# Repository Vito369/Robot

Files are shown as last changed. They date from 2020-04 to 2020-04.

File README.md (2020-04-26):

# Robot

## Authoři

Piskoř Dominik, Tkadlec Prokop, Vitoslavský Ondřej,Viater Dominik

## Úvod

Cílem práce je navrhnout autonomního mobilního robota, který dokáže sledovat černou
izolační pásku na bílém podkladu. Zároveň dokáže kamerou snímat překážky vyskytující se na
pásce a srážet je nebo se jim vyhýbat v závislosti na typu překážky. Překážky jsou dvojího
typu a to zombie (zelená překážka) a silničář (červená překážka).

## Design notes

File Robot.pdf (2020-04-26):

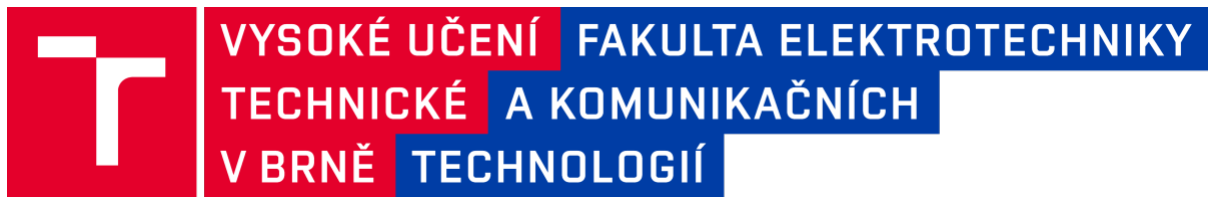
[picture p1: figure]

# Autonomní mobilní robot

## Tým: Snad dojedem

Autoři: | Vitoslavský Ondřej Piskoř Dominik Tkadlec Prokop Viater Dominik

# Obsah

# Úvod

Cílem práce je navrhnout autonomního mobilního robota, který dokáže sledovat černou izolační pásku na bílém podkladu. Zároveň dokáže kamerou snímat překážky vyskytující se na pásce a srážet je nebo se jim vyhýbat v závislosti na typu překážky. Překážky jsou dvojího typu a to zombie (zelená překážka) a silničář (červená překážka).

# Hardware

Robot obsahuje následující hardware:

- Šasi a střechu
- Vyhodnocovací jednotku (RaspberryPi 4)
- Rozšiřovací desku s I2C, GPIO a ADC (Mainboard)
- Modul KM2 pro řízení krokových motorů
- Dva krokové motory pro diferenciální podvozek
- Desku se dvěma optočleny a LED
- Kameru
- Baterie li-pol 18650

# Model

Šasi vozidla je vyrobená technologií 3D tisku z materiálu PLA. Zatímco šasi je tištěna s infilem 100%, střecha je tištěna pouze s 20 %. Šasi se skládá ze tří oddělených částí: část pro motory a kameláž k nim vedoucí, část pro desku s optočleny a poslední část je určena pro Raspberry, modul pro ovládání krokových motorů a kameru.

Vzdálenost optočlenů od osy motorů byla zvolena 40mm, tedy nejmenší, které bylo možno s testovací deskou dosáhnout. Šasi rovněž obsahuje otvory pro kameru, pro krokové motory a montáž všesměrové kovové kuličky která je použita jako třetí opěrný bod celého robotu

Střecha obsahuje otvory na napájecí adaptér, kabely pro připojení baterie a otvor pro tlačítka umístěné na Raspberry. Na vrchní straně střechy je bateriový držák navržen pro 4 kusy lithiových článků.

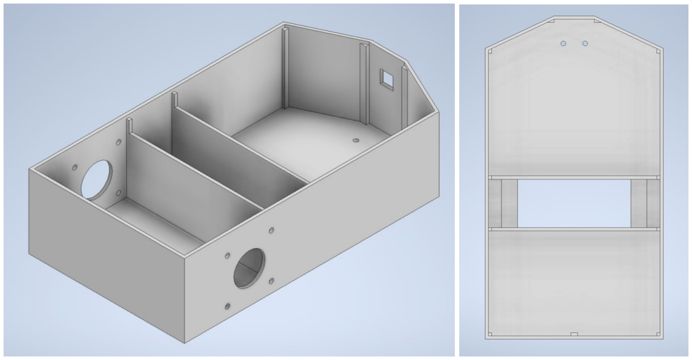
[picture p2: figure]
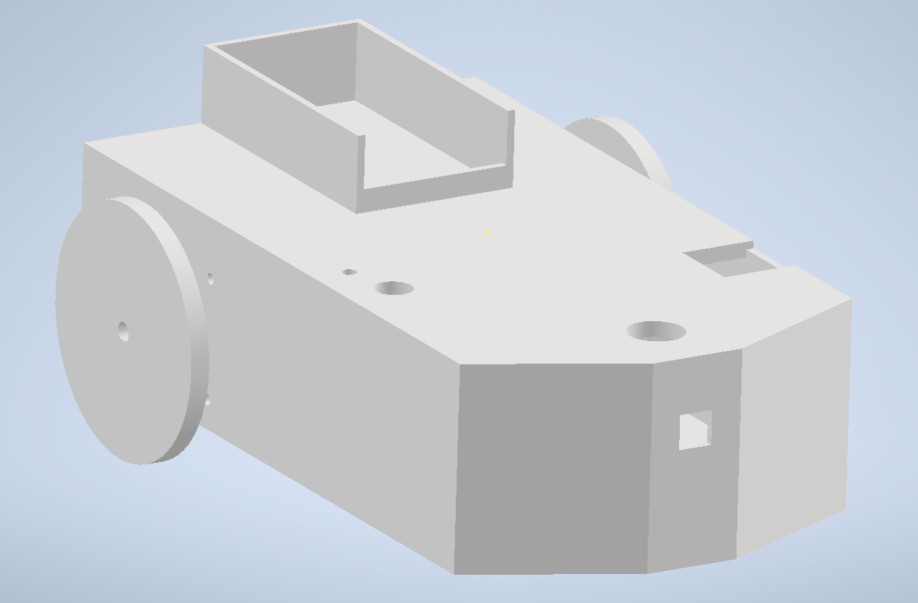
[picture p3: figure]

# Deska s optočleny

Deska je použita testovací, tedy ta, kterou měli k dispozici všechny týmy. Obsahuje dva optočleny a dvě bílé LED, zajišťující stálé pracovní podmínky při různé intenzitě okolního osvětlení.

Umístění optočlenů bylo zvoleno 12 mm od podlahy a každý z optočlený je vzdálený 5 mm od středu robotu. Na grafu č 1. je vidět závislost dvou optočlenů na vzdálenosti od středu izolační pásky a jejich lineární náhrady, které jsou použity při výpočtech vzdálenosti programu.

Pro výpočet vzdálenosti jsou třeba 4 základní body:

1. Maximální hodnota z ADC (bílý papír).
2. Minimální hodnota z ADC (černá izolační páska – nesmí být měřeno na křížovatce).
3. Hodnota, ve které se obě charakteristiky protnou (vzdálenost středu robotu od pásky je 0 mm).
4. Hodnota jednoho optočlenu, při které je druhý optočlen ve své minimální hodnotě.

Způsob vyhodnocování

Najde se optočlen s nejmenší výstupní hodnotou, tedy ten, který je nejblíže izolační pásce. Poté se zjistí, jestli je hodnota na druhém optočlenu větší nebo menší než základní bod č 4. – pokud je tato hodnota menší než základní bod č. 4, nachází se střed robotu do 5 mm od středu izolační pásky (v Grafu č. 1 oblast -5 až 0 mm nebo 0 až 5 mm). Je-li tato hodnota naopak větší, tak je střed robotu více než 5 mm vzdálený od izolační pásky
(v Grafu č. 1 oblast -20 až -5 mm nebo 5 až 20 mm).

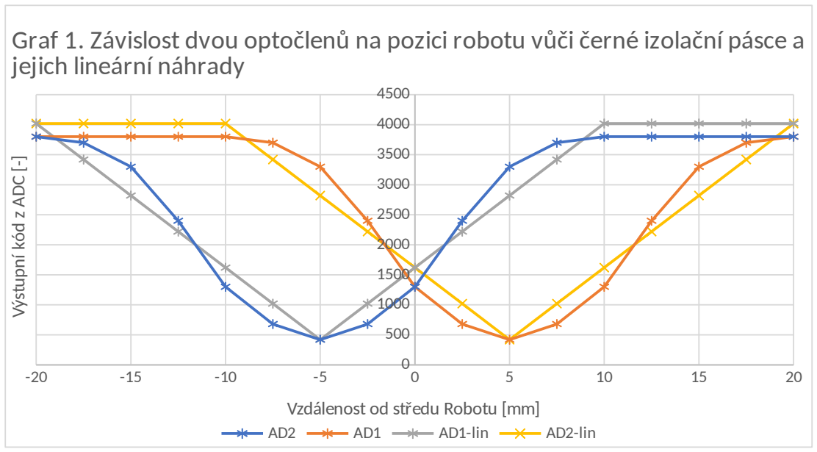
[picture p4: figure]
jejich lineární náhrady; AD1-lin; AD2-lin; Vzdálenost od středu Robotu [mm]; Výstupní kód z A

Graf 1. Závislost dvou optočlenů na pozici robotu vůči černé izolační pásce a

# Motory a kola

V robotu jsou použity dva krokové motory SX17-1005-QCEF, které jsou ovládány modulem KM-2, se kterým se komunikuje za pomocí I²
C. Kola robotu mají průměr 65 mm, jsou od sebe vzdáleny 135 mm, každé tedy 67,5 mm od středu robotu.

Pro zpětnovazební regulaci úhlové rychlosti a tedy vzdálenosti středu robotu od izolační pásky je použit PS regulátor se složkou Kp=0,5 a Ki=0,9. Zesílení složky P bylo navrženo na takovou hodnotu, při které dokázal robot bez problémů projet zatáčkou o průměru 50 mm při rychlosti

v=

s
t

=

obvodkola
1s

=

200mm
1s

=20 cm∗s

−1

Zesílení složky I pak bylo navrženo tak, aby se zpomalil regulační děj a tedy zlepšila plynulost jízdy robotu. Zavedení složky D do regulátoru způsobovalo rozkmitání robotu, především však při najetí do křižovatky nebo rozdělení. Složka D byla proto odebrána.

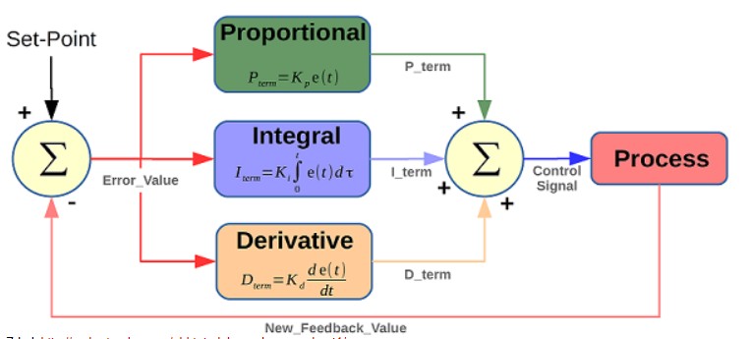
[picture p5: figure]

Ovládání lineární rychlosti robotu je realizováno druhým regulátorem, ten má však pevně nastavenou žádanou hodnotu. Je tedy použit pouze pro plynulý rozjezd po startu robotu. Regulace lineární rychlosti v závislosti na průměru zatáčky se nepodařilo odladit z důvodu řešení případu, kdy by mohlo dojít k přerušení vodící čáry v zatáčce.

# Řešení přerušení čáry

Robot si po celou dobu jízdy uchovává úhlové rychlosti za posledních 500 ms (doba běhu hlavní supersmyčky je 50 ms). V případě ztráty kontaktu s izolační páskou se robot podívá do paměti jakou měl úhlovou rychlost před tím, než z pásky vyjel a s touto úhlovou rychlostí pokračuje. Po najetí robotu zpět na pásku se vrací do původního režimu jízdy.

# Kamera a snímání překážek

Robot má snímat a vyhodnocovat dva typy překážek a to Silničáře a Zombie. Z důvodů zmenšení doby běhu supersmyčky byla větev pro vyhodnocení zombie zcela odebrána.

Použitá knihovna bpc_prp_opencv_lib

Postup zpracování a vyhodnocení:

1. Pořízení fotky
2. Rozmazání snímku kvůli redukci šumu
3. Zmenšení fotky kvůli zmenšení potřebného výpočetního výkonu
4. Rozdělení na BGR složky, ze kterých nás tedy zajímá pouze složka R – červená
5. Převod původní fotky z BGR na odstíny šedi (GREY)
6. Treshold červené složky na R obrázku na 150/255 a šedé složky na GREY na 100/255
7. Vytvoření masky, tedy průnik obrázku R a negace obrázku GREY, dojde tedy
k odstranění všech bílých objektů, které se ve složce R jeví také jako červené. Tím dostaneme obrázek (matici) ve které se nachází pouze oblasti, ve kterých původně červená barva skutečně byla.
8. Vytvoření kernelu a použití morfologie otevírání (opening) kdy se nejdříve na obrázek aplikuje eroze a poté dilatace. Erozí se zbavíme malých oblastí, které můžou být způsobeny například odrazy od stěn v pozadí. Dilatací pak zvětšíme všechny zbylé objekty, které v ideálním případě „srostou“ v jeden objekt (za předpokladu, že kamera opravdu zabírá jen jednu překážku).
9. Vyhodnocení počtu, pozic a velikostí jednotlivých objektů vzniklých na konečném obrázku.

Způsob objetí překážky:

V momentě, kdy je překážka před robotem vyhodnocena jako červená (silničář) je zahájena nová větev programu. V té se robot otočí o 90 stupňů a obloukem o průměru přibližně 30 cm překážku začne objíždět. Zastaví se tehdy, najede-li zpět na černou pásku, kde se otočí do původního směru jízdy a pokračuje dále. Objetí selže v případě, že se nachází více izolačních pásek vedle sebe, Robot se totiž napojí na první pásku, na kterou narazí.

# Závěr

Robot dokáže následovat černou pásku na bílém podkladu (popřípadě podkladu jiné barvy, za předpokladu předchozí kalibrace). Dokáže se vyhnout červené překážce stojící na pásce a najet za překážkou zpět na pásku a pokračovat v jízdě. Dokáže pokračovat v jízdě po úmyslném přerušení pásky a to jak při přímé jízdě, tak v zatáčkách.

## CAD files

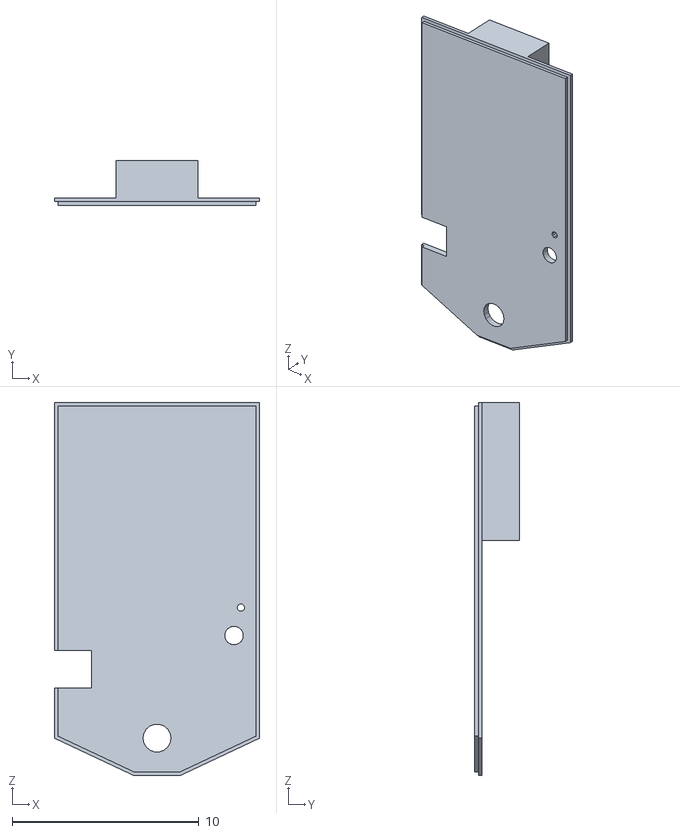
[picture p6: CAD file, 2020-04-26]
Hw/Strecha.stl
11.0 x 2.40 x 20.0

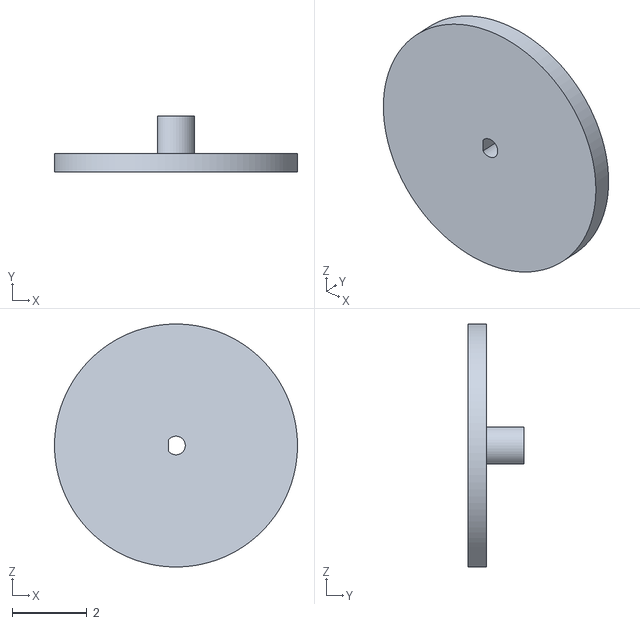
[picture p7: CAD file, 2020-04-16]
Hw/kolo.stl
6.50 x 1.50 x 6.50

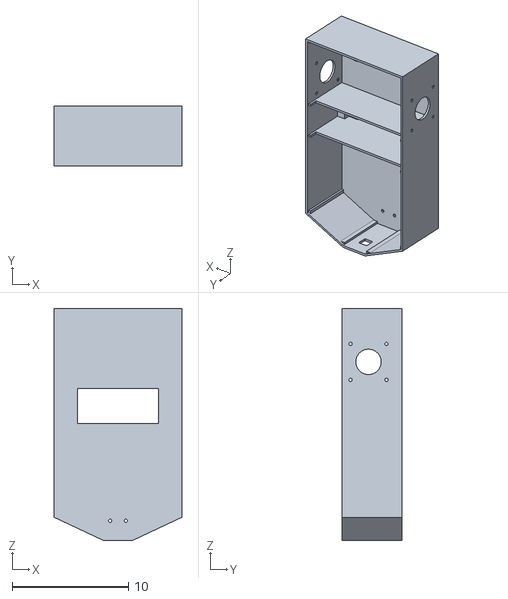
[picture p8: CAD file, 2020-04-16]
Hw/Robot.stl
11.0 x 5.20 x 20.0

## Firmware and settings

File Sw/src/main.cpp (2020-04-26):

#include <iostream>
#include <chrono>

#include <opencv4/opencv2/opencv.hpp>
#include <opencv4/opencv2/core/mat.hpp>

#include <bpc_prp_opencv_lib/ImageProcessor.h>
#include <bpc_prp_opencv_lib/utils.h>
#include <zconf.h>


#include "../inc/C_GPIO.h"
#include "../inc/C_ADC.h"
#include "../inc/C_MOTORS.h"
#include <cmath>

#define I2C_BUS_NUMBER  1
#define CAMERA 1
#define STARTUP_SETTING 0

uint16_t SAMPLE_TIME=50; //time in ms



enum _State{
    NORMAL,
    CROSSING,
    OUT_OF_TAPE,
    WORKER,
    TESTING
}State=NORMAL;


const char *graf(char* buffer, int nchars, float value);

float PSDController1 (float desiredValue, float measuredValue);
float PSDController2 (float desiredValue, float measuredValue);

int main(int argc, char* argv[])
{
    uint32_t millis=0;
    float ang=0, spd=0;
    float prev_ang[6]={0.};
    float distance=0;

    //GPIO
    C_GPIO GPIO(I2C_BUS_NUMBER, 0, GPIO_I2C_ADDRESS);
    GPIO.i2c_init();
    GPIO.GPIO_Init();
    //ADC
    C_ADC ADC(I2C_BUS_NUMBER,GPIO.get_fd(),ADDR_AD799X_0_L);
    ADC.Set_Config(AD799X_CONFIG_FLTR|AD799X_CONFIG_CH_ALL);
    (void)ADC.Read_Register(AD799X_CONFIG);
    //MOTORS
    C_MOTORS MOTORS(I2C_BUS_NUMBER,GPIO.get_fd(),ADDR_KM2_DEFAULT);

    //START
    GPIO.Beep(10,1000);
#if CAMERA
    //CAMERA
    bpc_prp_opencv_lib::ImageProcessor imgProcessor(false, false, "/home/pi/images/");
    cv::VideoCapture cap;
    if(!cap.open(0)) {
        std::cerr << "Error, unable to open camera" << std::endl;
        return -1;
    }
    cv::Mat frame;
    cap >> frame;
    if( frame.empty() ) {
        std::cerr << "Error, frame is empty" << std::endl;
        return -2;
    }
#endif
#if STARTUP_SETTING
    while(1){
        ADC.Read_Sensors();
        (void)ADC.Calculate_Distance(1);
        ADC.Print_Info();

        if((GPIO.Button_Read(PA7)==true)&&(GPIO.Button_Read(PA6)==true)){
            break;
        }
        usleep(SAMPLE_TIME*1000);
    }
    GPIO.Beep(10,1000);
    GPIO.Beep(10,1000);
    GPIO.Beep(10,1000);
#endif
    GPIO.LED_ON(PB6);
    while(1) {
        //start of clock
        auto start = std::chrono::high_resolution_clock::now();
        std::cout << "=======================================" << std::endl;
        switch(State){
            case NORMAL:
            {
                ADC.Read_Sensors();
                distance=ADC.Calculate_Distance(0);
                std::cout << "dis: " << distance << std::endl;

                if(ADC.Is_Crossing()){
                    State=CROSSING;
                    break;
                }

                if(ADC.Is_Outside_the_Tape(distance)){
                    State=OUT_OF_TAPE;
                    break;
                }

                spd=PSDController1(C_WHEEL/1.5,MOTORS.get_speed_linear());
                ang=-PSDController2(0,distance);


                MOTORS.Set_Speed(spd+MOTORS.get_speed_linear(),ang);
                //MOTORS.Position_Info();

                prev_ang[5]=prev_ang[4];
                prev_ang[4]=prev_ang[3];
                prev_ang[3]=prev_ang[2];
                prev_ang[2]=prev_ang[1];
                prev_ang[1]=prev_ang[0];
                prev_ang[0]=ang;
#if CAMERA
                cap >> frame;
                auto detections = imgProcessor.analyzeImage(frame);

                std::cout << detection.getTypeAsString()<<" "<< detection.getDistance() <<" "<<detection.getDirection() << std::endl;
                if(detection.getDistance()==1){
                    State=WORKER;
                }

#endif
                break;
            }
            case CROSSING:
            {
                for(uint8_t i=0;i<3;i++){
                    MOTORS.Set_Speed(spd+MOTORS.get_speed_linear(),prev_ang[5]);
                    Delay_ms(SAMPLE_TIME);
                }
                State=NORMAL;

                break;
            }
            case OUT_OF_TAPE:
            {
                ADC.Read_Sensors();
                distance=ADC.Calculate_Distance(0);
                MOTORS.Set_Speed(spd+MOTORS.get_speed_linear(),(prev_ang[4]+prev_ang[5])/2.);
                //MOTORS.Position_Info();
                if(!ADC.Is_Outside_the_Tape(distance)){
                    State=NORMAL;
                }
                break;
            }
            case WORKER:
                {
                    MOTORS.Set_Speed(0,0);
                    GPIO.Beep(100,1000);

                    //right 90 degree turn
                    for(int i=0;i<18;i++){
                        MOTORS.Set_Speed(0,M_PI_2);
                        Delay_ms(SAMPLE_TIME);
                    }
                    MOTORS.Set_Speed(0,0);
                    GPIO.Beep(100,1000);


                    for(int i=0;i<150;i++){
                        MOTORS.Set_Speed(C_WHEEL/1.5,-M_PI/4.);
                        ADC.Read_Sensors();
                        distance=ADC.Calculate_Distance(0);
                        std::cout << "dis: " << distance << std::endl;
                        if((i>10)&&((distance>-10.)&&(distance<10.))&&(distance!=0.)){
                            GPIO.Beep(10,0);
                            break;
                        }
                        Delay_ms(SAMPLE_TIME);
                    }
                    MOTORS.Set_Speed(0,0);

                    spd=0;
                    ang=0;
                    prev_ang[5]=0;
                    prev_ang[4]=0;
                    prev_ang[3]=0;
                    prev_ang[2]=0;
                    prev_ang[1]=0;
                    prev_ang[0]=0;
                    State=NORMAL;
                break;
            }
            case TESTING:
                {

                cap >> frame;
                auto detections = imgProcessor.analyzeImage(frame);
                for(const auto& detection : detections){
                    std::cout << detection.getTypeAsString()<<" "<< detection.getDistance() <<" "<<detection.getDirection() << std::endl;
                    if(detection.getDistance()==1){
                        GPIO.LED_ON(PA0);
                        State=WORKER;
                    }
                    else{
                        GPIO.LED_OFF(PA0);
                    }
                }
                Delay_ms(SAMPLE_TIME);
                break;
            }
            default:
                break;
        }



        if((GPIO.Button_Read(PA7)==true)&&(GPIO.Button_Read(PA6)==true)){
            printf("Ended in %.2f seconds.\n",millis/1000.);
            GPIO.LED_OFF(PB1|PB6);
            break;
        }

        auto stop = std::chrono::high_resolution_clock::now();
        auto duration = std::chrono::duration_cast<std::chrono::microseconds>(stop - start);
        //std::cout << "Duration [ms]: " << duration.count()/1000 << std::endl;
        millis+=(SAMPLE_TIME);

        if((duration.count()/1000)>50.) continue;
        else if((duration.count()/1000)<50.){
            Delay_ms(SAMPLE_TIME-(duration.count()/1000));
        }

        auto stop2 = std::chrono::high_resolution_clock::now();
        auto duration2 = std::chrono::duration_cast<std::chrono::microseconds>(stop2 - start);
        //std::cout << "Duration2 [ms]: " << duration2.count()/1000 << std::endl;
        std::cout << "==================================" << std::endl;
    }
    GPIO.Buzzer_OFF();
    MOTORS.Set_Speed(0,0);
    return 0;
}


void Delay_ms(uint32_t time){
    usleep(1000*time);
}


float PSDController1 (float desiredValue, float measuredValue) {
    float error=0, output=0;

    error = desiredValue - measuredValue;
    output = 0.05*error;

    return output;
}

float PSDController2 (float desiredValue, float measuredValue) {
    float error, integral, derivative, output;
    static float previous_error2;

    error = desiredValue - measuredValue;
    integral = integral + error*(SAMPLE_TIME/1000.);
    derivative = (error - previous_error2)/(SAMPLE_TIME/1000.);
    output = 0.5*error + 0.9*integral + 0.*derivative;
    //output = 0.2*error + 0.5*integral + 0.*derivative;
    previous_error2 = error;
    return output;
}

// funkce na vytvoreni jedne hodnoty grafu do konzole
// buffer ... predalokovany pracovni buffer do ktereho se bude zapisovat text
// nchars ... pocet znaku v bufferu
// val ... hodnota (0...1) k vytisteni
// navratovou hodnotu lze rovnou pouzit jako parametr do printf ("%s", s)
const char *graf(char* buffer, int nchars, float value)
{
    int end = (int)(value * nchars) - 3; // start pipe, end pipe a koncova nula

    buffer[0] = '|';
    int i=1;

    while (i < end)
        buffer[i++] = '=';

    buffer[i++] = '|';

    while (i < (nchars-1))
        buffer[i++] = ' ';

    buffer[nchars-2] = '|';
    buffer[nchars-1] = 0;
    return buffer;
}

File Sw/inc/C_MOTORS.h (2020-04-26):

//
// Created by Ondra on 20.03.2020.
//

#ifndef DOJDEM_C_MOTORS_H
#define DOJDEM_C_MOTORS_H

#include "C_I2C.h"
#include "km2.h"
#include "cmath"


//
#define C_TW    0.135 //width of car in m
#define D_WHEEL 0.0660 //diameter of wheel in m

#define C_WHEEL (D_WHEEL*M_PI) //circumference of wheel in m
#define C_KM2 262. //write_to_reg=(tim*rot)/((f/M)*(step/(microstep*360)))=[rot/s]*262
#define C_LR C_KM2/C_WHEEL

extern uint16_t SAMPLE_TIME;
extern void Delay_ms(uint32_t time);


class C_MOTORS : public C_I2C {
    float linear_speed, angular_speed;
    int16_t right_wheel_speed, left_wheel_speed;
    float x_position, y_position, distance_traveled,distance_from_start;
    float angle;

public:

    C_MOTORS(int busnumber, int descriptor, int address): C_I2C(busnumber, descriptor, address)
    {
      linear_speed=0; angular_speed=0; right_wheel_speed=0; left_wheel_speed=0;
      x_position=0; y_position=0; distance_traveled=0, distance_from_start=0;
      angle=0;
    }

/**
 * Set linear and angular speed of robot
 *
 * @param linear linear speed of robot in m/s
 * @param angular angular speed of robot in rad/s
 */
    void Set_Speed(float linear, float angular){
        //calculate actual position
        Position_Calculate(linear_speed,angular_speed);
        int16_t pole[2];

        if(isnanf(angular)) {
            std::cerr << "ang isnan" << std::endl;
            angular=0;
        }
        linear_speed=linear;
        angular_speed=angular;

        //left_wheel_speed=(int16_t)(linear_speed+0.5*C_TW*angular_speed)*C_LR;
        //right_wheel_speed=-(int16_t)(linear_speed-0.5*C_TW*angular_speed)*C_LR;

        left_wheel_speed=(linear_speed+0.5*0.135*angular_speed)*(262./(0.066*M_PI));
        right_wheel_speed=-(linear_speed-0.5*0.135*angular_speed)*(262./(0.066*M_PI));

        pole[0]=left_wheel_speed;
        pole[1]=right_wheel_speed;
        if(left_wheel_speed>700) pole[0]=700;
        if(right_wheel_speed>700) pole[1]=700;
        if(left_wheel_speed<-700) pole[0]=-700;
        if(right_wheel_speed<-700) pole[1]=-700;

        std::cout << "left: " << left_wheel_speed  << "\tright: " << right_wheel_speed << std::endl;
        std::cout << "linear: " << linear_speed  << "\tangular: " << angular_speed << std::endl;
        i2c_write_leint16_array(get_fd(), get_i2c_address(), KM2_SPEED, &pole[0], 2);


    }

/**
 * Calculate all
 *
 * @param linear linear speed of robot in m/s
 * @param angular angular speed of robot in rad/s
 */
    void Position_Calculate(float linear, float angular){
        distance_traveled=distance_traveled+abs(linear*SAMPLE_TIME/1000.);
        angle=angle+angular*SAMPLE_TIME/1000.;
        x_position=x_position+sin(angle)*linear*SAMPLE_TIME/1000.;
        y_position=y_position+cos(angle)*linear*SAMPLE_TIME/1000.;
        distance_from_start=hypotf(x_position,y_position);
    }


    float get_speed_linear(void){
        return linear_speed;
    }

    float get_speed_angular(void){
        return angular_speed;
    }

    float get_distance_traveled(void){
        return distance_traveled;
    }

    float get_distance_from_start(void){
        return distance_from_start;
    }

    float get_angle(void){
        return angle;
    }

    void Position_Info(void){
        printf("x [cm] = %.2f \ty [cm] = %.2f \tangle [°] = %.2f\n",x_position*100,y_position*100,angle*180/M_PI);
    }
};


#endif //DOJDEM_C_MOTORS_H

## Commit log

2020-04-16 Hw Chasis
    [Robot.ipt, Robot.stl, kolo.ipt]
2020-04-16 added Kolo.stl
    [kolo.ipt]
2020-04-16 deleted ipt formats 2
    [Robot.ipt, kolo.ipt, kolo.stl]
2020-04-26 added Strecha.stl
    [Strecha.stl]
